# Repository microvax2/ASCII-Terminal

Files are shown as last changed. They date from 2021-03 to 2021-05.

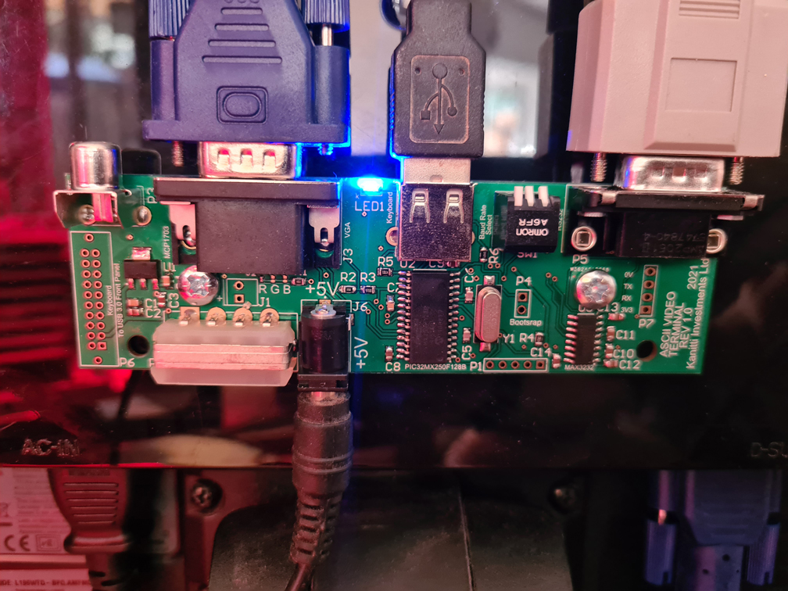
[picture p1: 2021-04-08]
Hooked up on the rear of a terminal, VESA mount.jpg

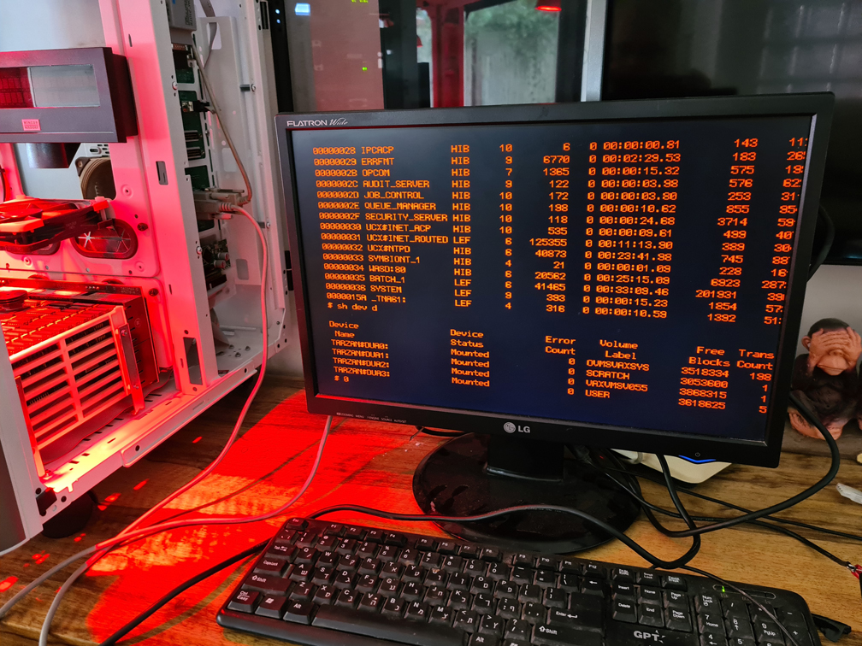
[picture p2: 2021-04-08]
Working as dumb terminal on a MicroVAX II.jpg

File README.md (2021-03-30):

# ASCII-Terminal
VT-100 Clone ASCII Terminal

VT100-Clone ASCII Terminal on a chip, this project is a new PCB designed around "Geoff's VT100 Terminal" by Geoff Graham, and the modified firmware designed by David Hansel  (https://github.com/dhansel/TerminalUSB) which supports a USB Keyboard.

Also inspired by Peter Hizalev's work (https://github.com/petrohi/terminal).

What is changed in this project is:

* SMT components used (except for the connectors, which I preferred to keep mechanically sound)
* The footprint is compatible with a VESA mount, so the PCB can be mounted directly to the rear of a VGA monitor using VESA mount screw holes (M4) 
* Removed PS/2 connector
* A standard type A USB connector, so a standard USB keyboard can be connected without any adaptors
* A USB 3.0 20-pin Header, for connecting a keyboard using a PC-style USB 2.0/3.0 front panel
* A 4-pin Molex ("Disk Drive") connector for powering the board from a PC-type power supply
* A 2.5mm DC jack connector for powering the board from a 5VDC wall wart power supply
* 3 DIP switches for selecting the baud rate
* 3 Solder bridges for selecting the text color (R/G/B)

The USB 3.0 header makes it possible to place the project in a PC Case, and connecting it to the front panel using the 20-pin USB 3.0 loom. Then, the PC case will become a "terminal housing": it will accept a USB keyboard on its front panel.

Please note: for a working terminal, not all the options need to be assembled:

* You need a type A USB connector (J7) *or* a 20-pin USB 3.0 header (P6), but probably not both
* You need to supply 5V power from P2, *or* from J1, *or* from J6, you need only one of them assembled
* If you need VGA output assemble J3. If you need Composite video output, assemble P3

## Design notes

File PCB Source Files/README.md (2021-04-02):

ALTIUM 21.2.2
PCB Source Files & Libraries

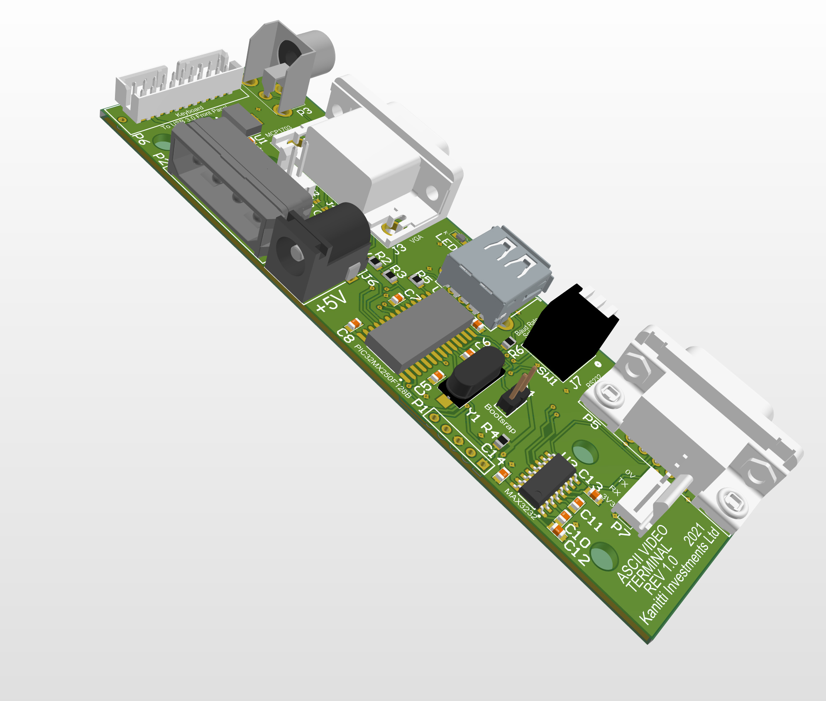
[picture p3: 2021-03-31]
3D/ASCII Terminal Overview II.jpg

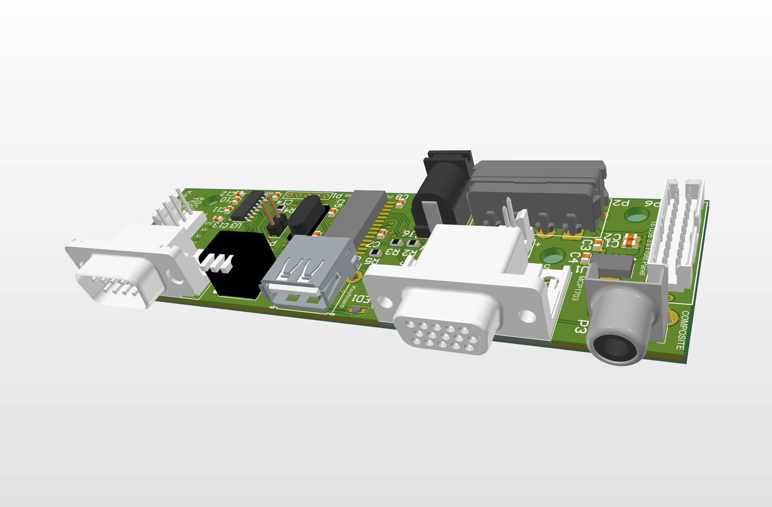
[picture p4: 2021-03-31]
3D/ASCII Terminal Overview I.jpg

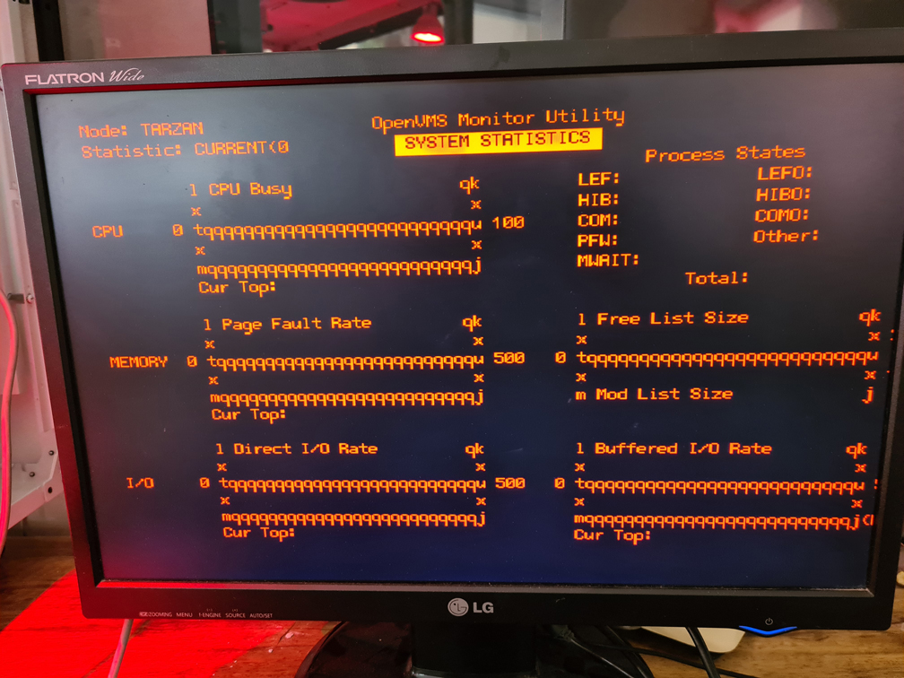
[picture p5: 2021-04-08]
VT100 'Graphics' Characters are Missing.jpg

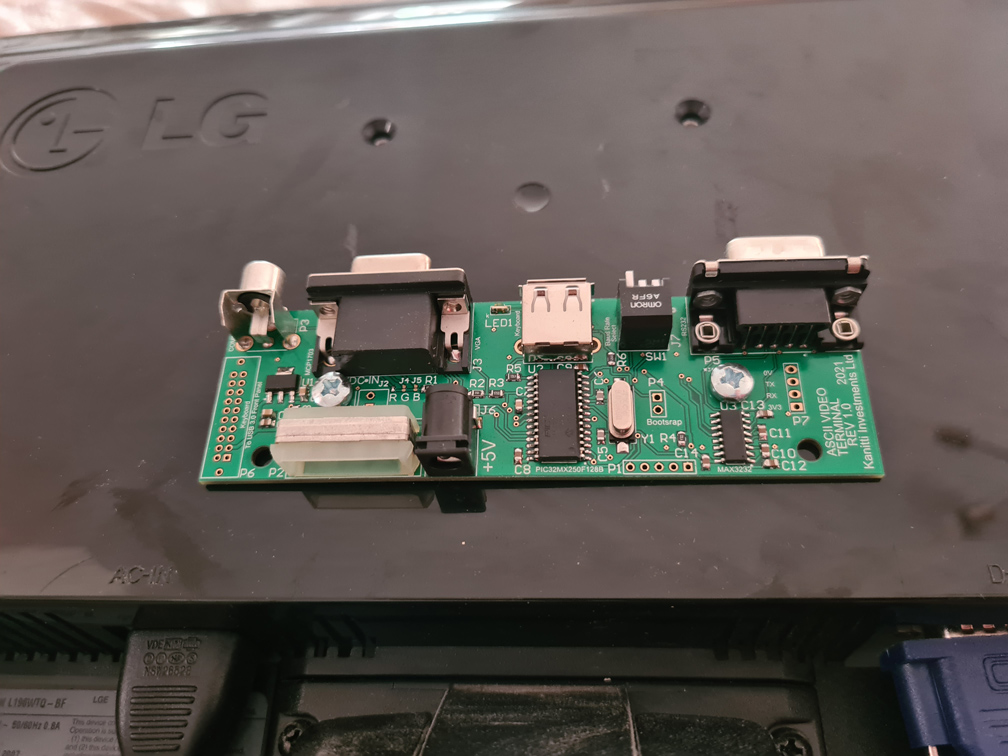
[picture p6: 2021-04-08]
Mounted.jpg

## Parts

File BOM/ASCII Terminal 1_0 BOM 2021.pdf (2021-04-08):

Component list | Bill of Materials for PCB Document [ASCII Terminal.PcbDoc]
Source Data From: | | ASCII Terminal.PcbDoc
Project: | | ASCII Terminal.PrjPcb
Variant: | | None
Report Date: | 29/03/21 | 11:43
Print Date: | 08-Apr-21 | 3:42:29 PM
# | Designator | P/N | Description | Value | Quantity

1 C1, C4, C7 | | LMK212ABJ106KG-T | Capacitor | 10 | 3
2 C2, C3, C8, C9, C10, C11, C12, C13, C14 | | UMK212BJ104KG-T | Capacitor | 0.1 | 9
3 C5, C6 | VJ0805A180FXXCW1BC | Capacitor | 18p | 2
4 J1 | 22232021 | Header, 2-pin | | 1
5 J3 | 2311763-1 | 15 Position D-Sub, High Density Receptacle, Female Sockets Connector | | 1
6 J6 | PJ-102B | Through Hole Right Angle DC Power Jack, 2.5 A, 2.5 mm Center Pin, 3 Position, -25 to 85 degC, RoHS, Bulk | | 1
7 J7 | 61400416021 USB 2.0 Type A Receptacle WR-COM, Horizontal, THT | 1
8 LED1 | LTST-S270KRKT | | | 1
9 P2 | 174552-1 | Header, 4-Pin | | 1
10 11 | P3 | RCJ-014 | RCA Phono Jack, Right Angle, Thru-Hole, Snap-In | | 1
| P4 | 61300211121 | THT Vertical Pin Header WR-PHD, Pitch 2.54 mm, Single Row, 2 pins | | 1
12 13 | P5 | 5747840-4 | Male D-Sub Connector, Pitch 1.37 mm, 9 Position, Height 12.93 mm, Tail Length 3.55 mm, -55 to 105 degC, RoHS, Tray | | 1
| P6 | T2M-110-01-L-D-TH-WT | High Reliability Cable Header, Through-hole, Vertical, -55 to 125 degC, 2 mm Pitch, 20-Pin, Male, RoHS | Can Also Use 87831-2019 | 1
14 15 | R1, R2 | CRCW0805150RFKEAC | RESISTOR | 150 | 2
| R3 | CRCW0805470RFKEAC | RESISTOR | 470 | 1
16 17 | R4, R5 | CRCW08054K70FKEAC | RESISTOR | 4K7 | 2
| R6 | CRCW080582R0FKEAC | RESISTOR | 82 | 1
18 19 | SW1 | A6FR-3104 | DIP SW (3) | | 1
| U1 | MCP1703T-330wE/DB | 250 mA, 16V, Low Quiescent Current LDO Regulator, 3-Pin SOT-223, Extended Temperature, Tape and Reel | | 1
20 21 | U2 | PIC32MX250F128B-I/SL | 32-bit Microcontroller with Audio and Graphics Interface, USB and | | 1
| U3 | MAX3232EIDR | Advanced Analog, 50 MHz, 19 I/O, PMP, -40 to 85 degC, 28-pin 3-V to 5.5-V Multichannel RS-232 Line Driver / Receiver with ±15-kV IEC ESD Protection, -40 to 85 degC, 16-Pin SOIC (D), Green (RoHS | | 1

### Approved

22 | Y1 | 9C-8.000MEEJ-T | 8MHz Â±10ppm Crystal 18pF 80 Ohms HC-49/US | 1
Notes | 35
Altium Limited Confidential | 08/04/21 | Page 1

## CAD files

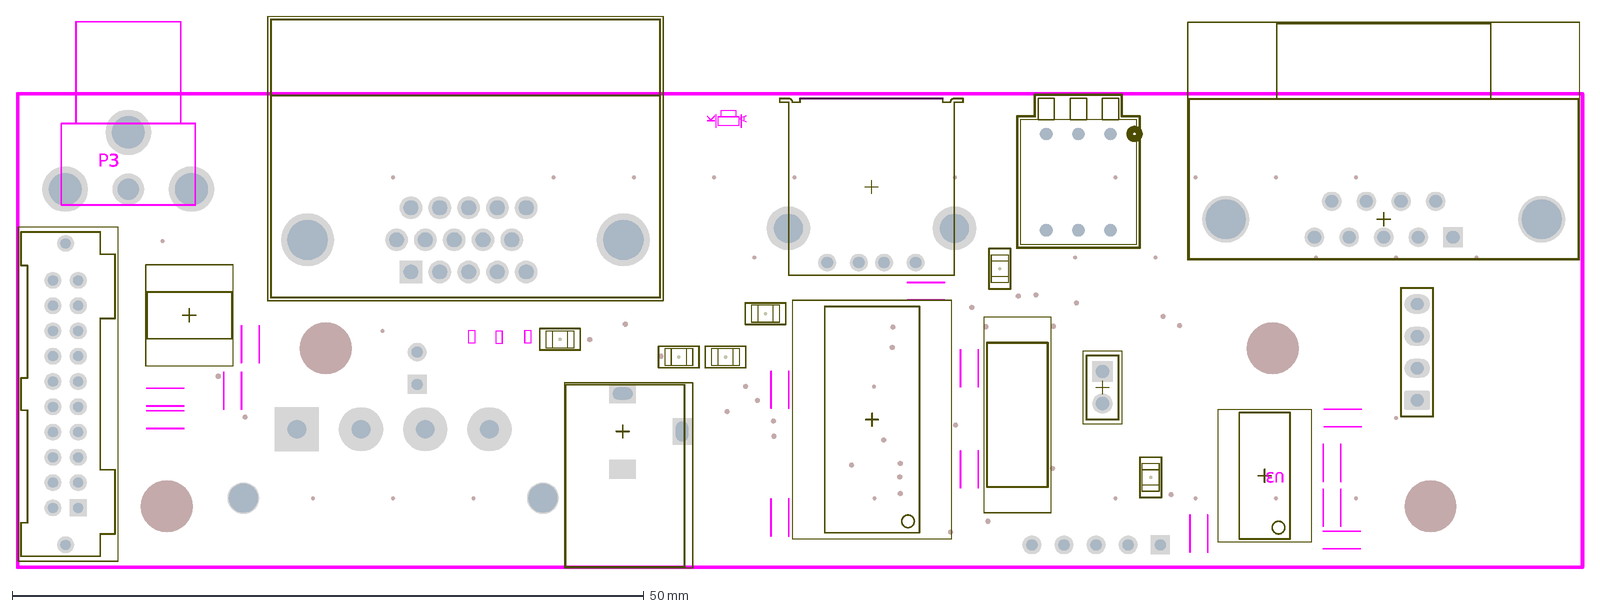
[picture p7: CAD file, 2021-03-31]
3D/ASCII Terminal DXF.DXF
U3
K
A
P3

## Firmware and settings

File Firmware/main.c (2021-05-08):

/*****************************************************************************************************************************

Main.c

	Copyright (C) 2014 Geoff Graham (projects@geoffg.net)
	All rights reserved.

	This file and the program created from it are FREE FOR COMMERCIAL AND
	NON-COMMERCIAL USE as long as the following conditions are aheared to.

	Copyright remains Geoff Graham's, and as such any Copyright notices in the
	code are not to be removed.  If this code is used in a product, Geoff Graham
	should be given attribution as the author of the parts used.  This can be in
	the form of a textual message at program startup or in documentation (online
	or textual) provided with the program or product.

	Redistribution and use in source and binary forms, with or without modification,
	are permitted provided that the following conditions  are met:
	1. Redistributions of source code must retain the copyright notice, this list
	   of conditions and the following disclaimer.
	2. Redistributions in binary form must reproduce the above copyright notice, this
	   list of conditions and the following disclaimer in the documentation and/or
	   other materials provided with the distribution.
	3. All advertising materials mentioning features or use of this software must
	   display the following acknowledgement:
	   This product includes software developed by Geoff Graham (projects@geoffg.net)

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
	The licence and distribution terms for any publically available version or
	derivative of this code cannot be changed.  i.e. this code cannot simply be copied
	and put under another distribution licence (including the GNU Public Licence).

********************************************************************************************************************************/

#define _SUPPRESS_PLIB_WARNING
#define _DISABLE_OPENADC10_CONFIGPORT_WARNING

#include <xc.h>
#include <sys/attribs.h>
#include <plib.h>									// peripheral libraries
#include <string.h>
#include <stdio.h>
#include <ctype.h>
#include "Terminal.h"
#include "video.h"
#include "vt100.h"

// declare the serial I/O functions
void initSerial(void);
int getSerial(void);
void putSerial(int c);

void initTimer(void);

void BlinkLED(void);
void SetUp(void);


char *SerialRxBuf;
int RxBufferSize;
volatile int SerialRxBufHead = 0;
volatile int SerialRxBufTail = 0;

#define SERIAL_TX_BUF_SIZE 256
char SerialTxBuf[SERIAL_TX_BUF_SIZE];
int SerialTxBufHead = 0;
int SerialTxBufTail = 0;

volatile int LEDTimer = 0;
int CursorOff = false;
volatile int CursorTimer = 0;
volatile int GeneralTimer;

#define MES_SIGNON  "\rASCII Video Terminal Ver " VERSION "\r\n"\
  "Copyright " YEAR " Geoff Graham\r\n" \
  "USB Keyboard support (c) 2018 David Hansel\r\n\r\n"


int main(int argc, char* argv[]) {
    int ch;

    SYS_Initialize(NULL);
    
	// initial setup of the I/O ports
    ANSELA = 0; ANSELB = 0;			                                // Default all pins to digital
    mJTAGPortEnable(0);                                             // turn off jtag

 	// setup the CPU
    SYSTEMConfigPerformance(CLOCKFREQ);    							// System config performance
	mOSCSetPBDIV(OSC_PB_DIV_1);									    // fix the peripheral bus to the main clock speed

    // clear all port I/O (they are not cleared by a software reset)
    LATA = LATB = 0;
    TRISA = TRISB = 0xffffffff;
    CNENA = CNENB = CNCONA = CNCONB = 0;
    CNPUA = CNPUB = CNPDA = CNPDB = 0;

    CNPUBSET = (1 << 4); CNPUBSET = (1 << 3); CNPUASET = (1 << 1);  // set pullups on the baudrate jumpers
    TRISBbits.TRISB5 = 0; LATBCLR = (1<<5);                         // turn on the power LED
    uSec(1000);                                                     // settling time

    INTEnableSystemMultiVectoredInt();                              // allow vectored interrupts
    initTimer();                                                    // initialise the millisecond timer
    initVideo();                                                    // initialise the video and associated interrupt
    initVT100();                                                    // initialise the vt100/vt52 decoding engine
    initFont(1);                                                    // set the default font
    initSerial();                                                   // initialise the UART used for the serial I/O
    initKeyboard();                                                 // initialise the keyboard and associated interrupt

    INTEnableInterrupts();

    uSec(100000);                                                   // allow everything to settle
	if(Option[O_STARTUPMSG]) VideoPrintString(MES_SIGNON); 			// print signon message

    while(1) {
        checkKeyboard();
        ShowCursor(true);

        ch = getSerial();
        if(ch != -1) VT100Putc(ch);

        if(KeyDown != -1) {
            switch(KeyDown) {
                case UP:        putSerialString(mode == VT100 ? "\033[A" : "\033A");      break;
                case DOWN:      putSerialString(mode == VT100 ? "\033[B" : "\033B");      break;
                case LEFT:      putSerialString(mode == VT100 ? "\033[D" : "\033D");      break;
                case RIGHT:     putSerialString(mode == VT100 ? "\033[C" : "\033C");      break;
                case HOME:      putSerialString("\033[1~");     break;
                case INSERT:    putSerialString("\033[2~");     break;
                case DEL:       putSerialString(/*"\033[3~"*/"\177");     break;
                case BKSP:      putSerialString("\177");         break;
                case END:       putSerialString("\033[4~");     break;
                case PUP:       putSerialString("\033[5~");     break;
                case PDOWN:     putSerialString("\033[6~");     break;
                case F1:        putSerialString("\033[11~");    break;
                case F2:        putSerialString("\033[12~");    break;
                case F3:        putSerialString("\033[13~");    break;
                case F4:        putSerialString("\033[14~");    break;
                case F5:        putSerialString("\033[15~");    break;
                case F6:        putSerialString("\033[17~");    break;
                case F7:        putSerialString("\033[18~");    break;
                case F8:        putSerialString("\033[19~");    break;
                case F9:        putSerialString("\033[20~");    break;
                case F10:       putSerialString("\033[21~");    break;
                case F11:       putSerialString("\033[23~");    break;
                case F12:       putSerialString("\033[24~");    break;
                case F3+0x20:   putSerialString("\033[25~");    break;
                case F12+0x20:  SetUp();                        break;
                default:        putSerial(KeyDown);             break;
            }
            KeyDown = -1;
            BlinkLED();
        }

    }
}



/*********************************************************************************************
* Serial I/O functions
**********************************************************************************************/

// initialize the UART2 serial port
void initSerial(void) {
    int cfg1, cfg2, baud = 0;
    if(Option[O_BAUDRATE] == -1) NVMWriteWord((void *)(&Option[O_BAUDRATE]), 1200); // the configurable baudrate defaults to 1200
    PPSInput(2, U2RX, RPB1); PPSOutput(4, RPB0, U2TX);

    TRISAbits.TRISA1 = 1; CNPUASET = (1 << 1); uSec(10000);         // something changes pin A1 (I wish I knew what) and this puts it back

    switch(PORTBbits.RB4 << 2 | PORTBbits.RB3 << 1 | PORTAbits.RA1) {
        case 7: baud = Option[O_BAUDRATE]; break;
        case 6: baud = 2400; break;
        case 5: baud = 4800; break;
        case 4: baud = 9600; break;
        case 3: baud = 19200; break;
        case 2: baud = 38400; break;
        case 1: baud = 57600; break;
        case 0: baud = 115200; break;
    }
    
    cfg1 = UART_ENABLE_PINS_TX_RX_ONLY;
    if(baud > 9000) cfg1 |= UART_ENABLE_HIGH_SPEED;
    if(!Option[O_SERIALINV]) cfg1 |= (UART_INVERT_RECEIVE_POLARITY | UART_INVERT_TRANSMIT_POLARITY);

    cfg2 = UART_DATA_SIZE_8_BITS;
    switch(Option[O_PARITY]) {
        case O_PARITY_NONE: cfg2 |= UART_PARITY_NONE;    break;
        case O_PARITY_ODD:  cfg2 |= UART_PARITY_ODD;     break;
        case O_PARITY_EVEN: cfg2 |= UART_PARITY_EVEN;    break;
    }
    cfg2 |= Option[O_1STOPBIT] ? UART_STOP_BITS_1 : UART_STOP_BITS_2;

    UARTConfigure(UART2, cfg1);
    UARTSetFifoMode(UART2, UART_INTERRUPT_ON_TX_NOT_FULL | UART_INTERRUPT_ON_RX_NOT_EMPTY);
    UARTSetLineControl(UART2, cfg2);
    UARTSetDataRate(UART2, BUSFREQ, baud);
    UARTEnable(UART2, UART_ENABLE_FLAGS(UART_PERIPHERAL | UART_RX | UART_TX));

    // Configure UART2 RX Interrupt (the Tx Interrupt is enabled in putSerial())
    INTSetVectorPriority(INT_VECTOR_UART(UART2), INT_PRIORITY_LEVEL_3);
    INTSetVectorSubPriority(INT_VECTOR_UART(UART2), INT_SUB_PRIORITY_LEVEL_0);
    INTEnable(INT_SOURCE_UART_RX(UART2), INT_ENABLED);
}


// UART 2 interrupt handler
void __ISR(_UART2_VECTOR, ipl3AUTO) IntUart2Handler(void) {

    if(INTGetFlag(INT_SOURCE_UART_RX(UART2))) {                     // Is this an RX interrupt?
        while(UARTReceivedDataIsAvailable(UART2)) {                 // while there is data to read
            if(UARTGetLineStatus(UART2) & 0b1110) {                 // first check for errors
                UARTGetDataByte(UART2);                             // and if there was an error throw away the char
                U2STACLR = 0b1110;                                  // clear the error on the UART
                continue;                                           // and try the next char
            }
            SerialRxBuf[SerialRxBufHead++]  = UARTGetDataByte(UART2); // store the byte in the ring buffer
            if(SerialRxBufHead >= RxBufferSize) SerialRxBufHead = 0;
            //SerialRxBufHead = SerialRxBufHead % RxBufferSize;
        }
        BlinkLED();
        INTClearFlag(INT_SOURCE_UART_RX(UART2));                      // Clear the RX interrupt Flag
    }

   if(INTGetFlag(INT_SOURCE_UART_TX(UART2))) {                      // Is this an Tx interrupt?
        while(UARTTransmitterIsReady(UART2) && SerialTxBufTail != SerialTxBufHead) { // while Tx is free and there is data to send
            INTDisableInterrupts();                                 // see Errata #10
            UARTSendDataByte(UART2, SerialTxBuf[SerialTxBufTail++]);// send the byte
            INTEnableInterrupts();
            SerialTxBufTail = SerialTxBufTail % SERIAL_TX_BUF_SIZE; // advance the tail of the queue
        }
        if(SerialTxBufTail == SerialTxBufHead)                      // if there is nothing left to send
            INTEnable(INT_SOURCE_UART_TX(UART2), INT_DISABLED);     // disable the interrupt
        INTClearFlag(INT_SOURCE_UART_TX(UART2));                    // Clear the Tx interrupt Flag
    }
}



// send a character to the Console serial port
void putSerial(int c) {
    SerialTxBuf[SerialTxBufHead++] = c;								// add the char
    SerialTxBufHead = SerialTxBufHead % SERIAL_TX_BUF_SIZE;         // advance the head of the queue
    INTEnable(INT_SOURCE_UART_TX(UART2), INT_ENABLED);              // enable Tx interrupt in case it was off
}


void putSerialString(char *p) {
    while(*p) putSerial(*p++);
}


// get a char from the UART1 serial port
// will return immediately with -1 if there is no character waiting
int getSerial(void) {
    char c;
    if(SerialRxBufHead == SerialRxBufTail) return -1;
    c = SerialRxBuf[SerialRxBufTail++];
    if(SerialRxBufTail >= RxBufferSize) SerialRxBufTail = 0;
    return c;
}


/*********************************************************************************************
* Timer functions
**********************************************************************************************/




/***************************************************************************************************
InitTimer - Initialise the 1 mSec timer used for internal timekeeping.
****************************************************************************************************/
void initTimer(void) {
 	// setup timer 4
    PR4 = 1000 * (BUSFREQ/2/1000000) - 1;                           // 1 mSec
    T4CON = 0x8010;         										// T4 on, prescaler 1:2
    mT4SetIntPriority(1);  											// lower priority
    mT4ClearIntFlag();      										// clear interrupt flag
    mT4IntEnable(1);       											// enable interrupt
}



/****************************************************************************************************************
Timer 4 interrupt processor
This fires every mSec and is responsible for tracking the time and the counts of various timing variables
*****************************************************************************************************************/
void __ISR( _TIMER_4_VECTOR, ipl1AUTO) T4Interrupt(void) {

    if(LEDTimer)
        if(--LEDTimer < 25) LATBCLR = (1<<5);

    if(GeneralTimer) GeneralTimer--;

    if(++CursorTimer > CURSOR_OFF + CURSOR_ON) CursorTimer = 0;		// used to control cursor blink rate

    // Clear the interrupt flag
    mT4ClearIntFlag();
}


void BlinkLED(void) {
    if(LEDTimer  == 0) {
        LEDTimer = 75;
        LATBSET = (1<<5);
    }
}





/////////////////////////////////////////////////////////////////////////////////////////////////////////////
// Macro to reserve flash memory for saving/loading options and initialise to 0xFF's
// creates an array of integers 'name' with 'nbr' elements
// Note that 'nbr' need to be a multiple of 256 to fit the PIC32MX150/250 erase page size which is 1024 bytes
#define NVM_ALLOCATE(name, nbr) int name[(nbr)] \
	     __attribute__ ((aligned(1024),space(prog),section(".nvm"))) = \
	     { [0 ...(nbr)-1] = 0xFFFFFFFF }

// allocate space in flash for the options.  The start of the memory is aligned on erasable page boundary
NVM_ALLOCATE(Option, 256);



void Prompt(int x, char *msg) {
    int i;
    for(i = 0; i < x; i++) VT100Putc(' ');
    VideoPrintString(msg);
}


void PPrompt(char *msg, char *current) {
    int i;
    if(vga) for(i = 0; i < 14; i++) VT100Putc(' ');
    VideoPrintString(msg);
    for(i = 0; i < (vga ? 38:30) - strlen(msg); i++) VT100Putc(' ');
    VideoPrintString("(currently ");
    VideoPrintString(current);
    if(vga)
        VideoPrintString(")     \r\n");
    else {
        VideoPrintString(")");
        for(i = 30 + strlen(current) + 13; i <=48; i++) VT100Putc(' ');
        VideoPrintString("\r\n");
    }
}


int GetInput(char *msg, int min, int max) {
    int i;
    if(vga) for(i = 0; i < (74 - strlen(msg))/2; i++) VT100Putc(' ');
    VideoPrintString(msg);
    cmd_ClearEOS();
    while(toupper(KeyDown) < min || toupper(KeyDown) > max) { checkKeyboard(); ShowCursor(true); }
    i = toupper(KeyDown);
    KeyDown = -1;
    VT100Putc(i);
    VideoPrintString("\r\n");
    return i;
}



void SetUp(void) {
    const char *kblang[8] = {"US", "FR", "GR", "IT", "BE", "UK", "RS" };
    const char *oparity[3] = {"8 NONE", "7 ODD", "7 EVEN" };
    char baud[10];
    #define NBR_SAVED   20
    int saved[NBR_SAVED], i;

    for(i = 0; i < NBR_SAVED; i++) saved[i] = Option[i];

    cmd_Reset();
    ConfigBuffers(true);
    ShowCursor(false);                                              // turn off the cursor to prevent it from getting confused
    ClearScreen();

    while(1) {
        CursorPosition(1, 1);
        if(vga) Prompt(35, ""); else Prompt(15, "");
        AttribUL = true;
        VideoPrintString("SET-UP MENU\r\n");
        AttribUL = false;
        if(vga) VideoPrintString("\r\n");
        PPrompt("A = Number of lines (for VGA)", saved[O_LINES24] ? "24" : "36");
        PPrompt("B = Composite output", saved[O_PAL] ? "PAL" : "NTSC");
        PPrompt("C = Keyboard language", (char *)kblang[saved[O_KEYBOARD] + 1]);
        if(vga) VideoPrintString("\r\n");
        PPrompt("D = Number of bits and parity", (char *)oparity[saved[O_PARITY] + 1]);
        PPrompt("E = Number of stop bits", saved[O_1STOPBIT] ? "ONE" : "TWO");
        PPrompt("F = Invert Serial (for RS232)", saved[O_SERIALINV] ? "OFF" : "INVERT");
        sprintf(baud, "%d", saved[O_BAUDRATE]);
        PPrompt("G = Configurable baudrate", baud);
        if(vga) VideoPrintString("\r\n");
        PPrompt("H = Display start up message", saved[O_STARTUPMSG] ? "ON" : "HIDE");
        if(vga) VideoPrintString("\r\n");
        Prompt((vga ? 14:0), "I = Reset to the original defaults\r\n");
        Prompt((vga ? 14:0), "J = Discard all changes and exit\r\n");
        Prompt((vga ? 14:0), "K = Save changes and restart terminal\r\n");

        VideoPrintString("\r\n");
        if(vga) VideoPrintString("\r\n");

        switch(GetInput("Select item (enter A to K) : ", 'A', 'K')) {
            case 'A': saved[O_LINES24] = GetInput("Enter 1 for 24 lines or 2 for 36 lines : ", '1', '2') - '2';
                      break;
            case 'B': saved[O_PAL] = GetInput("Enter 1 for PAL or 2 for NTSC : ", '1', '2') - '2';
                      break;
            case 'C': if(vga)
                          saved[O_KEYBOARD] = GetInput("Language 1=US, 2=FR, 3=GR, 4=IT, 5=BE, 6=UK, 7=ES : ", '1', '7') - '2';
                      else
                          saved[O_KEYBOARD] = GetInput("1=US, 2=FR, 3=GR, 4=IT, 5=BE, 6=UK, 7=ES : ", '1', '7') - '2';
                      break;
            case 'D': saved[O_PARITY] = GetInput("1 = 8bit NONE, 2 = 7bit ODD, 3 = 7bit EVEN : ", '1', '7') - '2';
                      break;
            case 'E': saved[O_1STOPBIT] = GetInput("Enter the number of stop bits : ", '1', '2') - '2';
                      break;
            case 'F': saved[O_SERIALINV] = GetInput("Enter 1 for normal or 2 for inverted : ", '1', '2') - '2';
                      break;
            case 'G': if(vga) for(i = 0; i < (74 - strlen("Enter baudrate as a number followed by ENTER : "))/2; i++) VT100Putc(' ');
                      VideoPrintString("Enter baudrate as a number followed by ENTER : ");
                      cmd_ClearEOS();
                      i = 0;
                      while(1) {
                          int j;
                          checkKeyboard();
                          mINT3IntEnable(false);       				// disable interrupt while we play
                          j = KeyDown;
                          KeyDown = -1;
                          mINT3IntEnable(true);
                          ShowCursor(true);
                          if(j == '\r') break;
                          if(j == '\b') { i = i /10; VideoPrintString("\b \b"); }
                          if(j >= '0' && j <= '9') { VT100Putc(j); i = (i * 10) + j - '0'; }
                      }
                      if(i == 0) i = saved[O_BAUDRATE];
                      if(i < 40) i = 40;
                      if(i > 1000000) i = 1000000;
                      saved[O_BAUDRATE] = i;
                      break;
            case 'H': saved[O_STARTUPMSG] = GetInput("Enter 1 to display or 2 to hide : ", '1', '2') - '2';
                      break;
            case 'I': for(i = 0; i < NBR_SAVED; i++) saved[i] = -1;
                      saved[O_BAUDRATE] = 1200;
                      break;
            case 'J': cmd_Reset();
                      return;
            case 'K': NVMErasePage((char *)Option);
                      for(i = 0; i < NBR_SAVED; i++) NVMWriteWord((void *)(&Option[i]), saved[i]);
                      SoftReset();
        }
    }
}



int GetFlashOption(const unsigned int *w) {
    return O_KEYBOARD_US;
}



#ifdef __DEBUG

void dump(char *p, int nbr) {
	char inpbuf[100], buf1[60], buf2[30], *b1, *b2;
	b1 = buf1; b2 = buf2;
	b1 += sprintf(b1, "%8x: ", (unsigned int)p);
	while(nbr > 0) {
		b1 += sprintf(b1, "%02x ", *p);
		b2 += sprintf(b2, "%c", (*p >= ' ' && *p < 0x7f) ? *p : ' ');
		p++;
		nbr--;
		if((unsigned int)p % 16 == 0) {
			sprintf(inpbuf, "%s   %s", buf1, buf2);
//			MMPrintString(inpbuf);
			b1 = buf1; b2 = buf2;
			b1 += sprintf(b1, "\r\n%8x: ", (unsigned int)p);
		}
	}
	if(b2 != buf2) {
		sprintf(inpbuf, "%s   %s", buf1, buf2);
//		MMPrintString(inpbuf);
	}
//	MMPrintString("\r\n");
}

#endif
 
